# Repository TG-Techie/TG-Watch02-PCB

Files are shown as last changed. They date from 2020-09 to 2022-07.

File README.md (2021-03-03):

# TG-Watch02-PCB
---

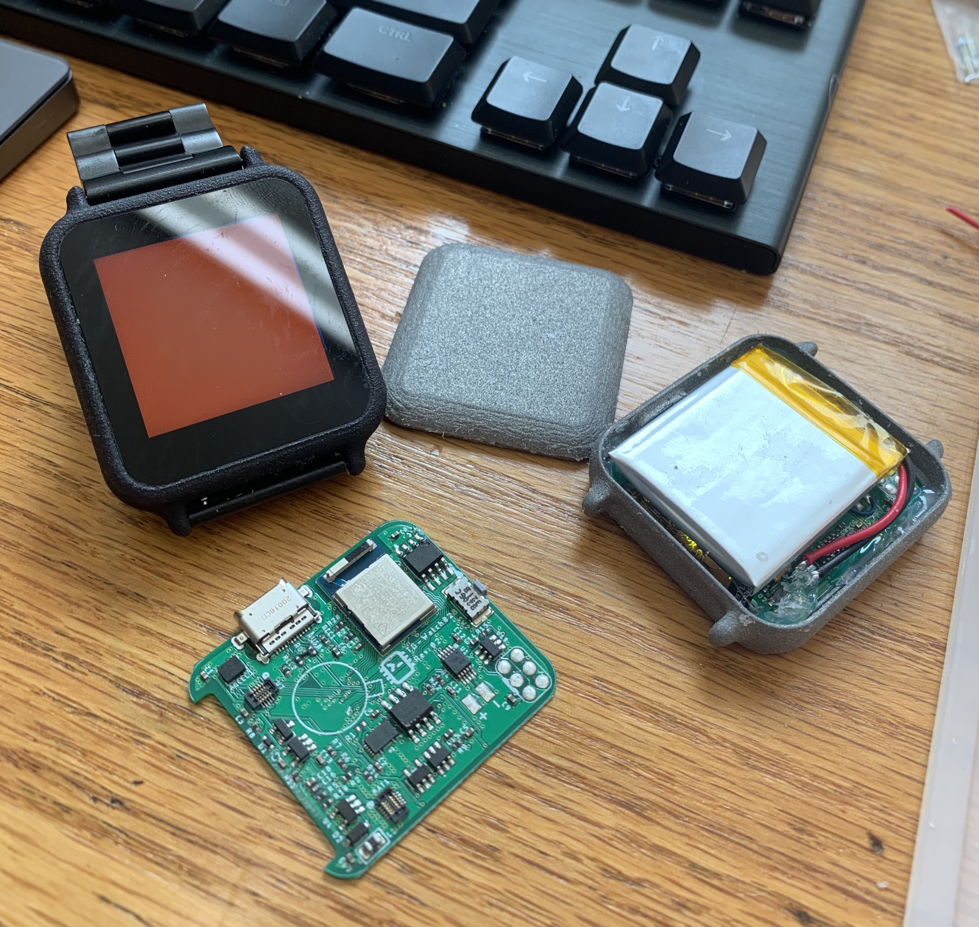
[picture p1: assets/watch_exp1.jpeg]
Image of watch


## Description
Why buy an apple watch when you can spend your weekends building a microcontroller based "smart" watch instead? the TG-Watch is an open source, not-dumb watch meant for makers who want to hack on their watch or as great starting point to learn about programming.

Some of its features include:
- a 240x240, 1.54" lcd
- capacitive touchscreen
- USB Type-C port (2.0)
- Step counter and pedometer
- vibration motor and haptic motor driver
- Bluetooth 5, Bluetooth mesh, Thread, ZigBee

## Software
The TG-Watch was designed to run circuitpython, this gives anyone the flexibility to run what they can write. Additionally, there is on-going development for a python GUI framework (TG-Gui-4 and TG-Gui 5) that runs on the watch. This framework is intended to make writing UI programs to run on the fun and approachable. (Currently under going a re-write)

## Examples
Updates about software and hardware are often posted to twitter, [here](https://twitter.com/TG_Techie).

## What's on it?
- 2295018-2, USB Type-C Connector
- LSM6DSOX, accel & gyro
- DRV2605, Haptic motor driver
- NRF52840, MCU and BLE IC
- BQ27441, battery charge tracker IC
- DS3231, real time clock

## Contribution and Questions
If you have any questions feel free to reach out and start a discussion on twitter at `@TG_Techie` or on discord at `@TG-Techie#5402`.

## License

Design and copyright by Jonah Yolles-Murphy, 2020

Creative Commons Attribution/Share-Alike, all text above must be included in any redistribution. See license.txt for additional details.

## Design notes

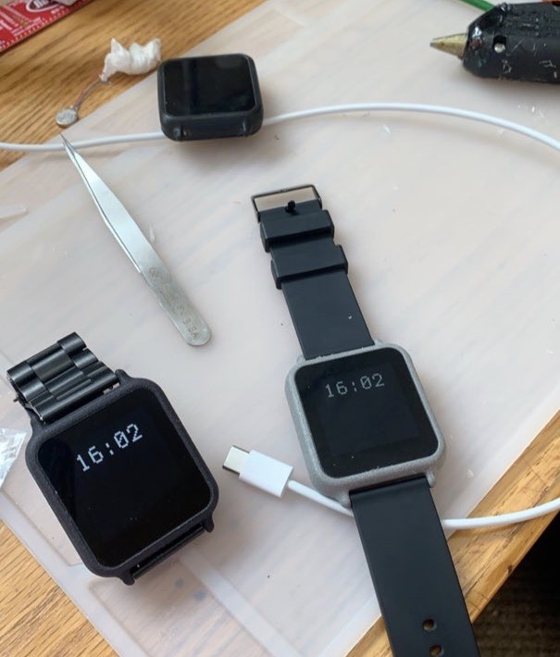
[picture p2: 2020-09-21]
assets/watch_exp0.jpeg

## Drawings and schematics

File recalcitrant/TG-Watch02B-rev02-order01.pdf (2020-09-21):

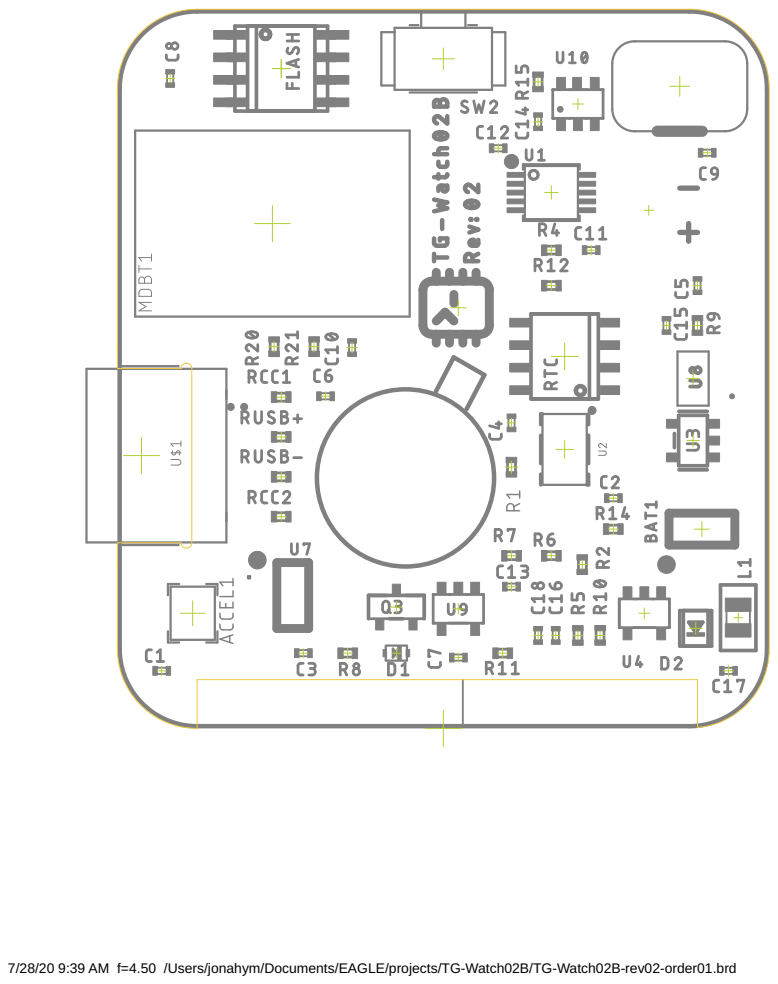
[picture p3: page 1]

7/28/20 9:39 AM f=4.50 /Users/jonahym/Documents/EAGLE/projects/TG-Watch02B/TG-Watch02B-rev02-order01.brd

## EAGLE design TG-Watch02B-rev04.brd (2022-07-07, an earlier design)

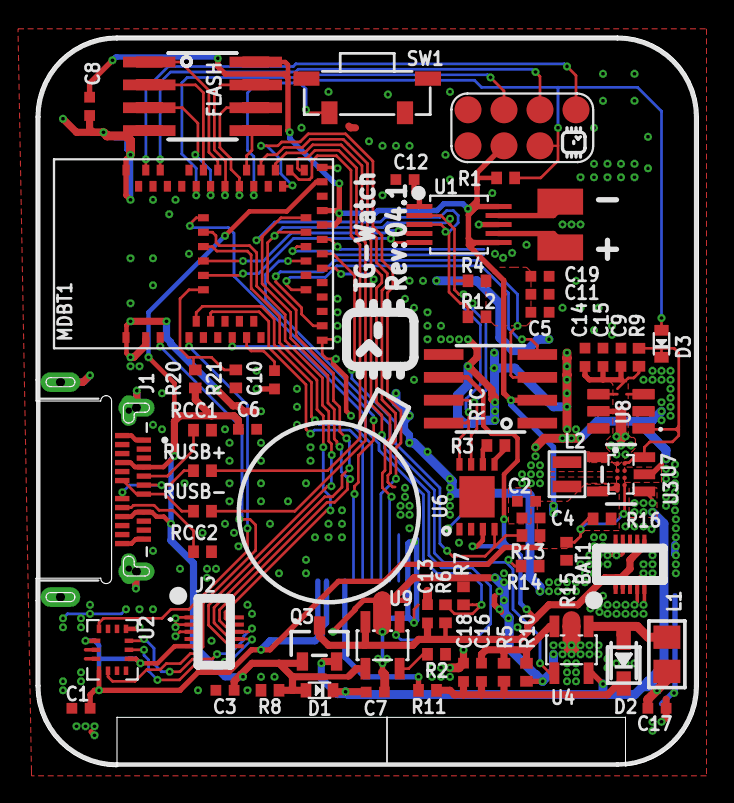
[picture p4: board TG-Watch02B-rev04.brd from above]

Board: 2 copper layers, 36.8 x 40.6 mm, 66 parts (0 on the bottom side), 56 nets.

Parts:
04.1: TG-Watch; TG-PROD-LABEL-5MM
C1, C18: 4.7uf; MICROBUILDER__0402_NODIMS
C2, C3, C4, C5, C6, C7, C8, C9, C13, C14, C15, C17, C19: 10uf; MICROBUILDER__0402_NODIMS
C10: 0.1uF; MICROBUILDER__0402_NODIMS
C11, C12: 1uf; MICROBUILDER__0402_NODIMS
C16: 0.1nF; MICROBUILDER__0402_NODIMS
D1: NSR05T40XV2; SOD-523
D2: BAT54T1G; SOD-323
D3: BAS16XV2T1G; SOD-523
FLASH: W25Q128JVSIQ TR; SOIC8_208MIL
HEDR2: 1X02SMD; 1X2_SMD
IC3: W25Q128JVSIQ TR; SOIC8_150MIL
J1: USB-C-CON-TG_MOD-2295018-2.0; TG_RM_TE_2295018-2
J2: DISP_1.54_LCMTF15423A-C_LCD+CAPTCH_ASSEMBLY_DUALS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; TF-LCM15423A-C_DUALSIDE
J3: CON-BAT-TG-MEZ_FEMALE; MEZ-DF37NC-10DS
L1: 10uH; 0805
L2: 1uH - HMLQ20161B-1R0MDR; NONSTANDARD_INDUCTOR_5
MDBT1: MDBT50
Q3: DMG2305; SOT23-R
R1, R10, R13, R14: 10k; TG_0402
R2: 2k; TG_0402
R3: 11k; TG_0402
R4, R9, R12, R21: 100k; TG_0402
R5: 68k; TG_0402
R6: 270k; TG_0402
R7, R16: 330k; TG_0402
R8: 2.7K; TG_0402
R11: 220R; TG_0402
R15: 59k; TG_0402
R20: 51k; TG_0402
RCC1, RCC2: 5.1k; TG_0402
RTC: SEN-TIME-DS3231-(PERSICION-TEMP); SOIC8_150MIL
RUSB+: 22ohm; TG_0402
RUSB-: 22ohm; TG_0402
SW1: MICROBUILDER_SPST_TACTILE_RA_NO_ALIGN
U1: MICROBUILDER_PSOP10
U2: MICROBUILDER_LSM6DSOX; MICROBUILDER_LGA-14L
U3: VREG-TPS63036; TPS63036YFGR_BGA8N40P4X2_NOSILK
U4: FAN5331SX; SOT23-5@1
U5: MCP73831/OT; SOT23-5L
U6: LC709203F; WDFN8_3X4_0.65
U7: SOT23-5
U8: UNDERVOLT-TPS3702CX3; SOT95P280X110-6N
U$3: CON_SWD_POGO; SWD_POGO

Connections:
3V3: C1.2, C2.2, C4.2, C5.2, C8.2, C11.2, C19.2, FLASH.8, IC3.8, J2.FPC11, J2.FPC12, J2.MEZ5, MDBT1.28, MDBT1.30, R1.2, R4.2, R12.2, R13.1, R16.1, RTC.2, U1.6, U1.10, U2.5, U2.8, U2.12, U3.D1, U7.5, U$3.6
9.6V: C16.1, C18.1, D2.C, R5.2, R11.2
ACCEL_INT1: MDBT1.4, U2.4
ACCEL_INT2: MDBT1.3, U2.9
AREF: C10.2, MDBT1.12
BAT_CHRG_SET: R2.2, U5.5
CC1: J1.A5, RCC1.2
CC2: J1.B5, RCC2.2
D6_BACKLIGHT: MDBT1.23, R14.2, U4.4
D9_RTC_RESET: MDBT1.19, RTC.4
D10_RTC_INT: MDBT1.16, RTC.3
D11_CHRG_STAT: MDBT1.22, U5.1
D12_BAT_INT: MDBT1.24, R13.2, U6.4
D14_VBUS_PRESENT: MDBT1.56, R20.1, R21.2
D15_HAPTIC_ENABLE: MDBT1.57, U1.5
D16_HAPTIC_INT: MDBT1.58, U1.4
D17_CTP_INT: J2.MEZ9, MDBT1.59
D18_CTP_RESET: J2.MEZ6, MDBT1.60
D19_TFT_RESET: J2.FPC8, MDBT1.61
D20_TFT_DC: J2.FPC6, MDBT1.5
D22_TFT_CS: J2.FPC7, MDBT1.7
D+: MDBT1.35, RUSB+.1
D-: MDBT1.34, RUSB-.1
DRV_REG: C12.2, U1.1
GND: C1.1, C2.1, C3.1, C4.1, C5.1, C6.1, C7.1, C8.1, C9.2, C10.1, C11.1, C12.1, C13.1, C14.1, C15.1, C17.1, C18.2, C19.1, FLASH.4, IC3.4, J1.A1, J1.A12, J1.B1, J1.B12, J1.P1_1, J1.P1_2, J1.P2_1, J1.P2_2, J1.P4, J1.P5, J2.FPC1, J2.FPC2, J2.FPC10, J2.MEZ1, J2.MEZ2, J2.MEZ3, J3.P$4, J3.P$5, J3.P$9, J3.P$10, MDBT1.1, MDBT1.2, MDBT1.15, MDBT1.33, MDBT1.55, R2.1, R7.1, R8.1, R10.1, R14.1, R15.1, R21.1, RCC1.1, RCC2.1, RTC.5, SW1.1, U1.8, U2.1, U2.6, U2.7, U3.B2, U3.C2, U4.2, U5.2, U6.1, U6.2, U7.2, U8.2, U$3.1, U$3.5
HAPTIC+: HEDR2.1, U1.7
HAPTIC-: HEDR2.2, U1.9
L1: L2.1, U3.B1
L2: L2.2, U3.C1
MOSI: J2.FPC4, MDBT1.37
unnamed: C16.2, R5.1, R10.2, U4.3
unnamed: D2.A, L1.2, U4.1
QSPI_CS: FLASH.1, IC3.1, MDBT1.44
QSPI_DATA0: FLASH.5, IC3.5, MDBT1.41
QSPI_DATA1: FLASH.2, IC3.2, MDBT1.46
QSPI_DATA2: FLASH.3, IC3.3, MDBT1.45
QSPI_DATA3: FLASH.7, IC3.7, MDBT1.43
QSPI_SCK: FLASH.6, IC3.6, MDBT1.42
RESET: D3.A, MDBT1.40, R1.1, SW1.2, U$3.7
SCK: J2.FPC5, MDBT1.36
SCL: J2.MEZ7, MDBT1.27, R4.1, RTC.8, U1.2, U2.13, U6.8
SDA: J2.MEZ8, MDBT1.29, R12.1, RTC.7, U1.3, U2.14, U6.7
SENSE: R15.2, R16.2, U3.D2
SWDCLK: MDBT1.53, U$3.4
SWDIO: MDBT1.51, U$3.3
SWO: MDBT1.47, U$3.2
SYS_EN: D3.K, R9.1, U3.A2, U7.3, U8.1
TSENSE: R3.2, U6.6
TSW: R3.1, U6.5
USBD+: J1.A6, J1.B6, RUSB+.2
USBD-: J1.A7, J1.B7, RUSB-.2
VBAT: C13.2, J3.P$1, J3.P$2, J3.P$6, J3.P$7, Q3.3, R6.2, RTC.6, U5.3, U6.3
VBUS: C3.2, C6.2, D1.A, J1.A4, J1.A9, J1.B4, J1.B9, MDBT1.32, Q3.1, R8.2, R20.2, U5.4
VDIV: MDBT1.10, R6.1, R7.2
VLED: J2.FPC9, R11.1
VSORS: C7.2, C9.1, C14.2, C15.2, C17.2, D1.K, L1.1, Q3.2, R9.2, U3.A1, U4.5, U7.1, U8.3, U8.4, U8.5

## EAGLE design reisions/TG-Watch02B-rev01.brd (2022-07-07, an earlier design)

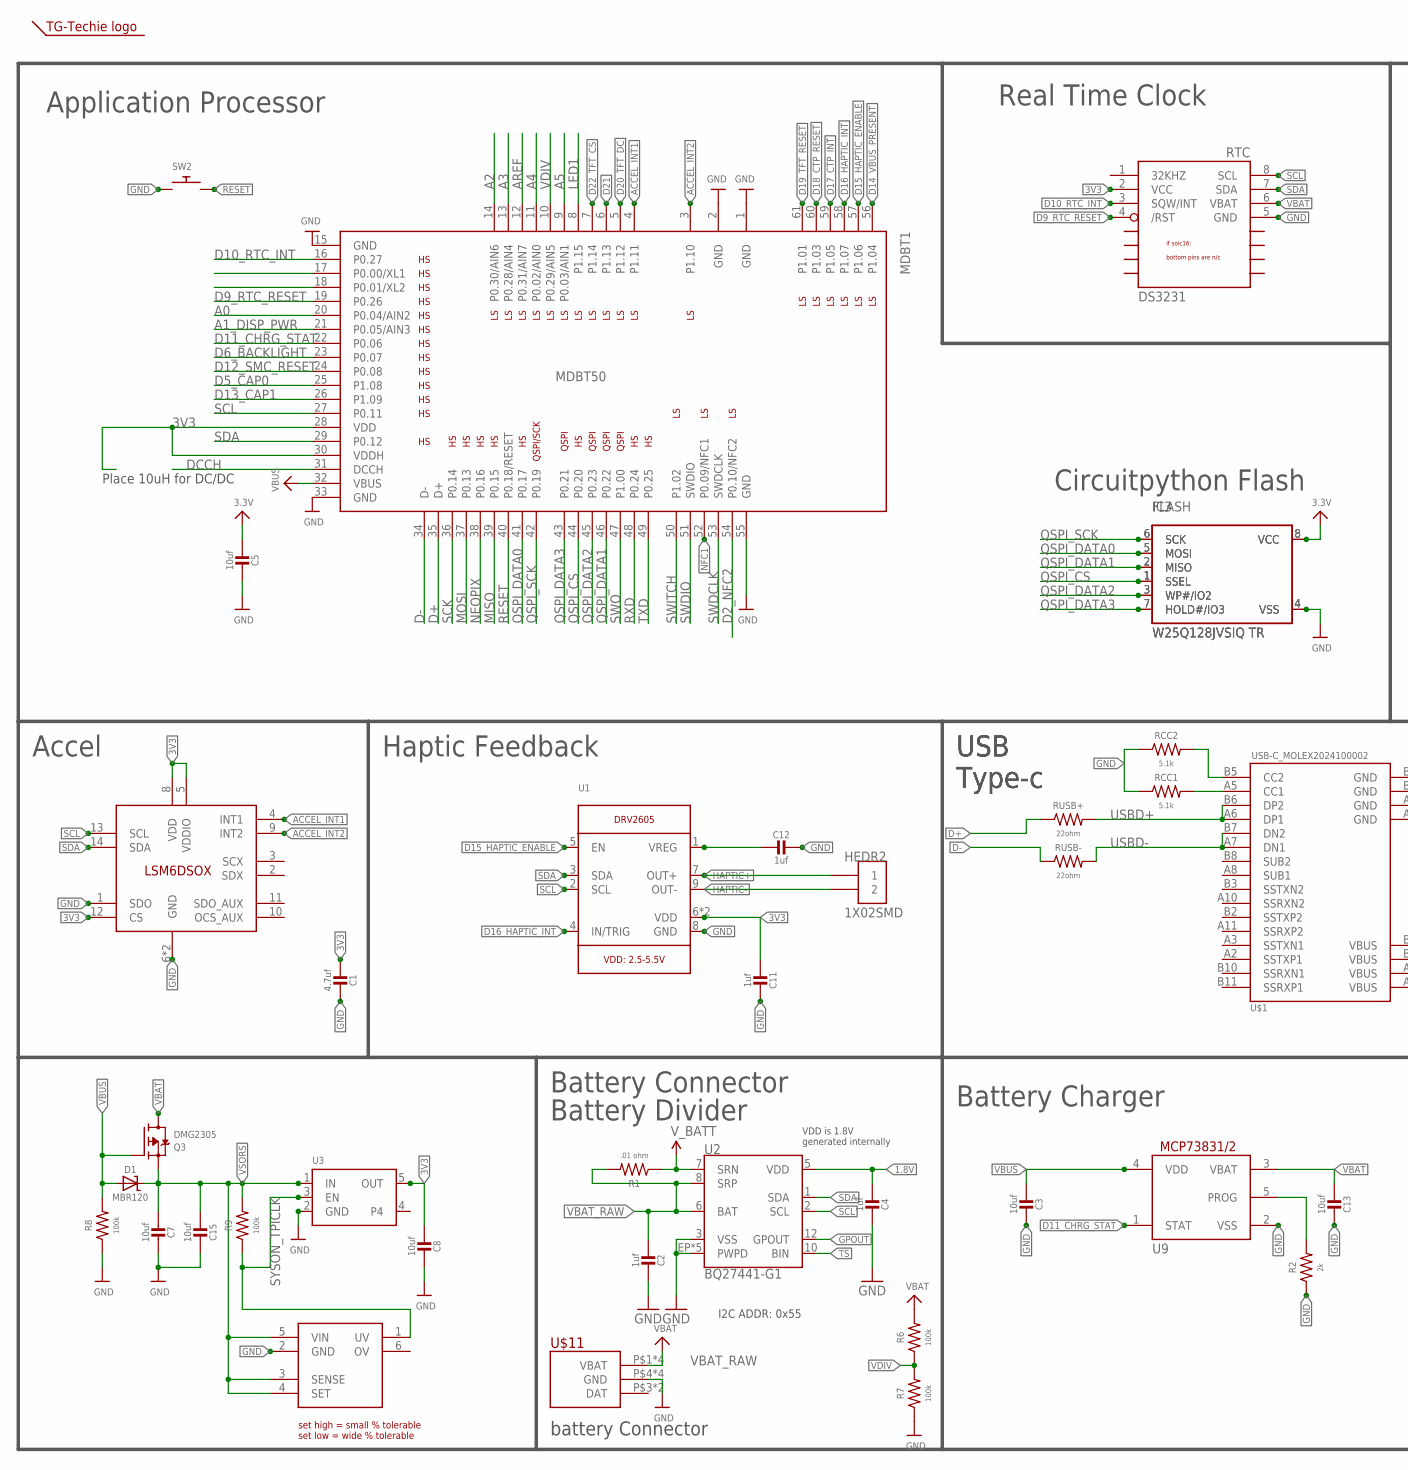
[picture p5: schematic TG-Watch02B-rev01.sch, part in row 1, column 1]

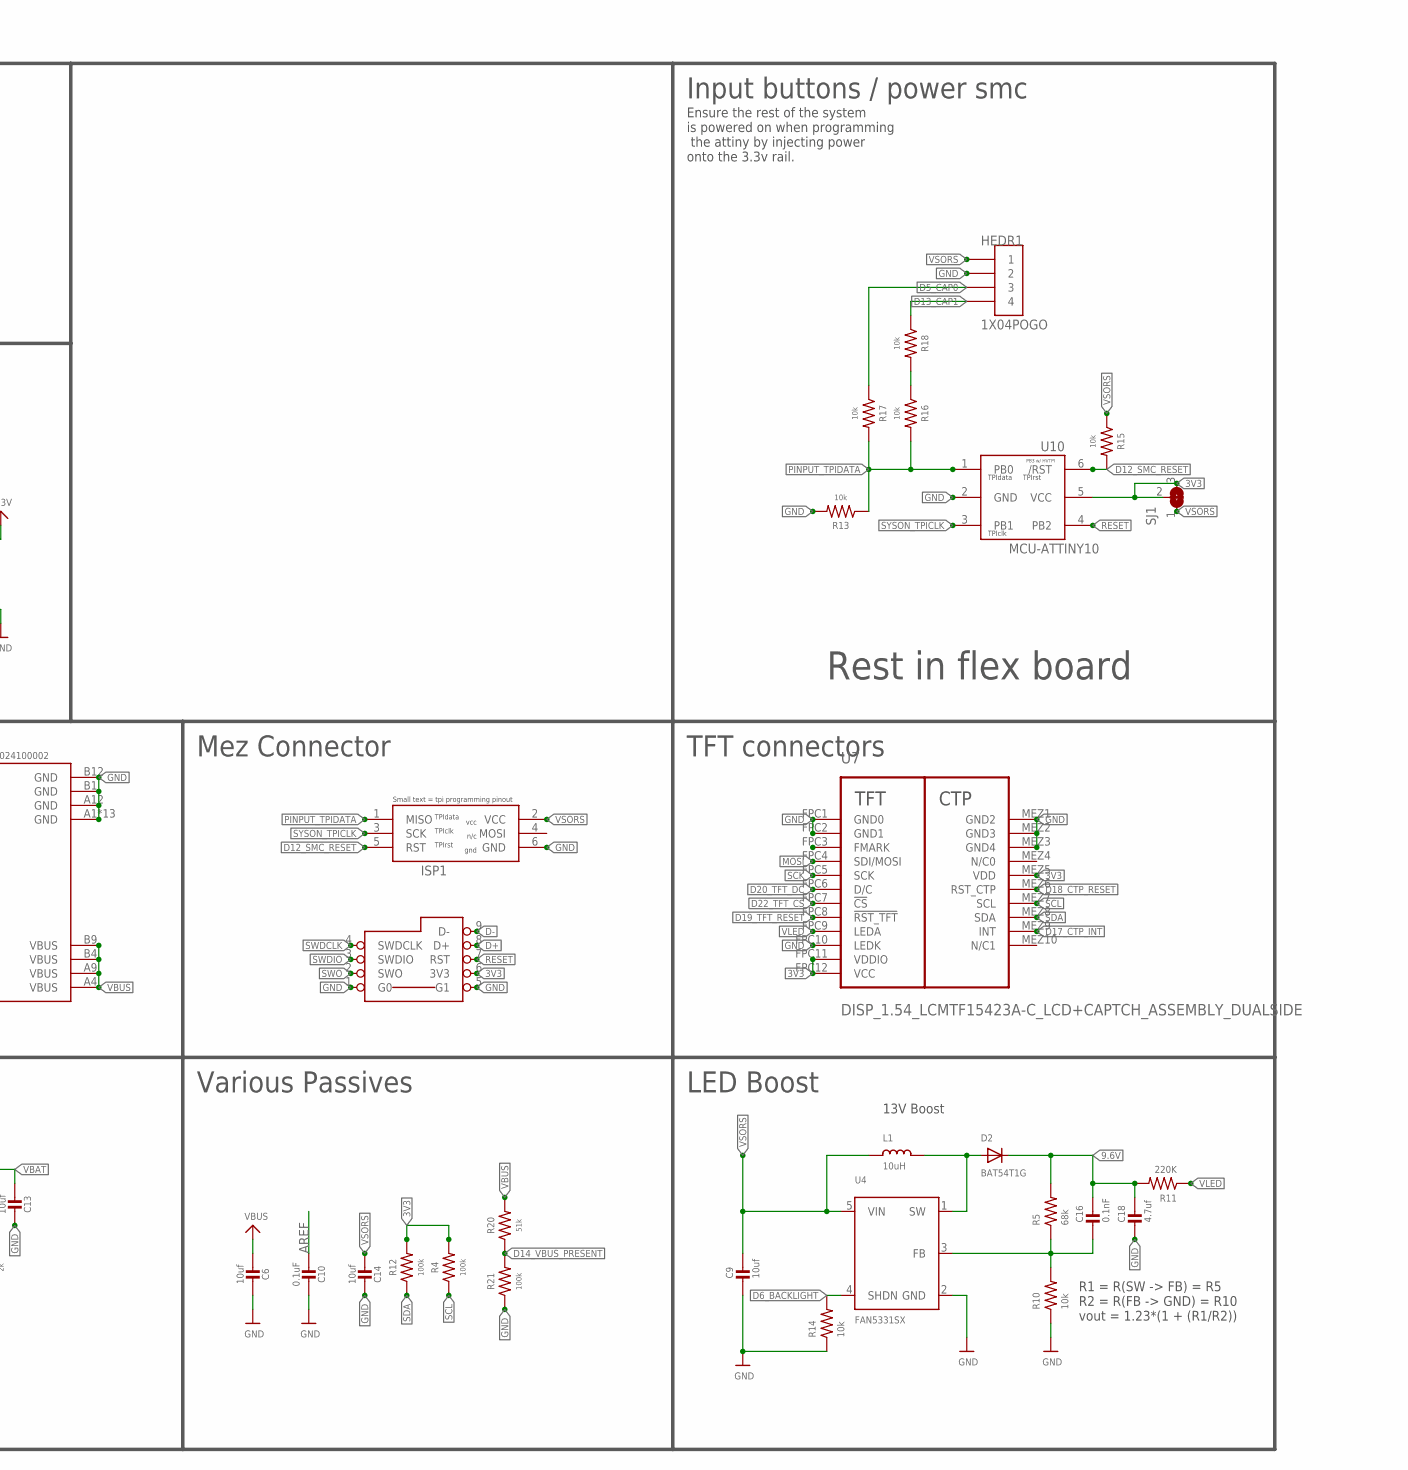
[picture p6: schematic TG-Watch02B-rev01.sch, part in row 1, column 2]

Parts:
C1, C18: 4.7uf; MICROBUILDER__0402_NODIMS
C2, C4, C11, C12: 1uf; MICROBUILDER__0402_NODIMS
C3, C5, C6, C7, C8, C9, C13, C14, C15: 10uf; MICROBUILDER__0402_NODIMS
C10: 0.1uF; MICROBUILDER__0402_NODIMS
C16: 0.1nF; MICROBUILDER__0402_NODIMS
D1: MBR120; SOD-523
D2: BAT54T1G; SOD-523
FLASH: W25Q128JVSIQ TR; SOIC8_208MIL
HEDR1: 1X04POGO; 1X4_POGO
HEDR2: 1X02SMD; 1X2_SMD
IC3: W25Q128JVSIQ TR; SOIC8_150MIL
ISP1: CON-ICSP/ISP-AVR-POGO; 2X3_POGO_AVR
L1: 10uH; 0805
MDBT1: MDBT50
Q3: DMG2305; SOT23-R
R1: .01 ohm; TG_0402
R2: 2k; TG_0402
R4, R6, R7, R8, R9, R12, R21: 100k; TG_0402
R5: 68k; TG_0402
R10, R13, R14, R15, R16, R17, R18: 10k; TG_0402
R11: 220K; TG_0402
R20: 51k; TG_0402
RCC1, RCC2: 5.1k; TG_0402
RTC: SEN-TIME-DS3231-(PERSICION-TEMP); SOIC8_150MIL
RUSB+: 22ohm; TG_0402
RUSB-: 22ohm; TG_0402
SJ1: JUMPER_OPEN_2_OP; SOLDERJUMPER_2WAY_OPEN_NOPASTE
SW2: SWITCH_PUSHBUTTONC&K_KSS; BTN_CK_KSS
U1: HAPTIC_DRIVER_DRV2605_SOP; MICROBUILDER_PSOP10
U2: BQ27441-G1; PDSO-N12
U3: VREG_STD_MIN_SOT23-5; SOT23-5
U4: FAN5331SX; SOT23-5@1
U7: DISP_1.54_LCMTF15423A-C_LCD+CAPTCH_ASSEMBLY_DUALS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; TF-LCM15423A-C_DUALSIDE
U8: UNDERVOLT-TPS3702CX3; SOT95P280X110-6N
U9: MCP73831/OT; SOT23-5L
U10: MCU-ATTINY10; SOT23-6
U$1: USB-C_MOLEX2024100002; USB-C_2024100002_MOLEX
U$3: MICROBUILDER_LSM6DSOX; MICROBUILDER_LGA-14L
U$11: CON-BAT-TG-MEZ_FEMALE; MEZ-DF37NC-10DS
U$13: CON_SWD_POGO_USB; SWD_POGO_USB
U$14: LOGO-TG-TECHIE5MM-SYMB; TG-LOGO-5MM-SYMB

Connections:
1.8V: C4.2, U2.5 (VDD)
3V3: C1.2, C5.2, C8.2, C11.2, FLASH.8 (VCC), IC3.8 (VCC), MDBT1.28 (VDD), MDBT1.30 (VDDH), R4.2, R12.2, RTC.2 (VCC), SJ1.2, SJ1.3, U1.6 (VDD), U1.10 (VDD), U3.5 (OUT), U7.FPC11 (VDDIO), U7.FPC12 (VCC), U7.MEZ5 (VDD), U10.5 (VCC), U$3.5 (VDDIO), U$3.8 (VDD), U$3.12 (CS), U$13.6 (3V3)
9.6V: C16.1, C18.1, D2.K (C), R5.2, R11.2
A0: MDBT1.20 (P0.04/AIN2)
A1_DISP_PWR: MDBT1.21 (P0.05/AIN3)
A2: MDBT1.14 (P0.30/AIN6)
A3: MDBT1.13 (P0.28/AIN4)
A4: MDBT1.11 (P0.02/AIN0)
A5: MDBT1.9 (P0.03/AIN1)
ACCEL_INT1: MDBT1.4 (P1.11), U$3.4 (INT1)
ACCEL_INT2: MDBT1.3 (P1.10), U$3.9 (INT2)
AREF: C10.2, MDBT1.12 (P0.31/AIN7)
BAT_CHRG_SET: R2.2, U9.5 (PROG)
CC1: RCC1.2, U$1.A5 (CC1)
CC2: RCC2.2, U$1.B5 (CC2)
D2_NFC2: MDBT1.54 (P0.10/NFC2)
D5_CAP0: HEDR1.3, MDBT1.25 (P1.08), R17.1
D6_BACKLIGHT: MDBT1.23 (P0.07), R14.2, U4.4 (SHDN)
D9_RTC_RESET: MDBT1.19 (P0.26), RTC.4 (/RST)
D10_RTC_INT: MDBT1.16 (P0.27), RTC.3 (SQW/INT)
D11_CHRG_STAT: MDBT1.22 (P0.06), U9.1 (STAT)
D12_SMC_RESET: ISP1.5 (RST), MDBT1.24 (P0.08), R15.2, U10.6 (/RST)
D13_CAP1: HEDR1.4, MDBT1.26 (P1.09), R18.1
D14_VBUS_PRESENT: MDBT1.56 (P1.04), R20.1, R21.2
D15_HAPTIC_ENABLE: MDBT1.57 (P1.06), U1.5 (EN)
D16_HAPTIC_INT: MDBT1.58 (P1.07), U1.4 (IN/TRIG)
D17_CTP_INT: MDBT1.59 (P1.05), U7.MEZ9 (INT)
D18_CTP_RESET: MDBT1.60 (P1.03), U7.MEZ6 (RST_CTP)
D19_TFT_RESET: MDBT1.61 (P1.01), U7.FPC8 (!RST_TFT)
D20_TFT_DC: MDBT1.5 (P1.12), U7.FPC6 (D/C)
D21: MDBT1.6 (P1.13)
D22_TFT_CS: MDBT1.7 (P1.14), U7.FPC7 (!CS)
D+: MDBT1.35 (D+), RUSB+.1, U$13.8 (D+)
D-: MDBT1.34 (D-), RUSB-.1, U$13.9 (D-)
DCCH: MDBT1.31 (DCCH)
DRV_REG: C12.2, U1.1 (VREG)
GND: C1.1, C2.1, C3.1, C4.1, C5.1, C6.1, C7.1, C8.1, C9.2, C10.1, C11.1, C12.1, C13.1, C14.1, C15.1, C18.2, FLASH.4 (VSS), HEDR1.2, IC3.4 (VSS), ISP1.6 (GND), MDBT1.1 (GND), MDBT1.2 (GND), MDBT1.15 (GND), MDBT1.33 (GND), MDBT1.55 (GND), R2.1, R7.1, R8.1, R10.1, R13.2, R14.1, R21.1, RCC1.1, RCC2.1, RTC.5 (GND), SW2.P$1, U1.8 (GND), U2.3 (VSS), U2.EP (PWPD), U2.EP1 (PWPD), U2.EP2 (PWPD), U2.EP3 (PWPD), U2.EP4 (PWPD), U3.2 (GND), U4.2 (GND), U7.FPC1 (GND0), U7.FPC2 (GND1), U7.FPC10 (LEDK), U7.MEZ1 (GND2), U7.MEZ2 (GND3), U7.MEZ3 (GND4), U8.2 (GND), U9.2 (VSS), U10.2 (GND), U$1.A1 (GND), U$1.A12 (GND), U$1.B1 (GND), U$1.B12 (GND), U$1.P$1 (GND), U$1.P$2 (GND), U$1.P$3 (GND), U$1.P$4 (GND), U$1.P$5 (GND), U$1.P$6 (GND), U$1.P$7 (GND), U$1.P$8 (GND), U$1.SHLD0 (GND), U$1.SHLD1 (GND), U$1.SHLD2 (GND), U$1.SHLD3 (GND), U$3.1 (SDO), U$3.6 (GND), U$3.7 (GND), U$11.P$4 (GND), U$11.P$5 (GND), U$11.P$9 (GND), U$11.P$10 (GND), U$13.1 (G0), U$13.5 (G1)
GPOUT: U2.12 (GPOUT)
HAPTIC+: HEDR2.1, U1.7 (OUT+)
HAPTIC-: HEDR2.2, U1.9 (OUT-)
LED1: MDBT1.8 (P1.15)
MISO: MDBT1.39 (P0.15)
MOSI: MDBT1.37 (P0.13), U7.FPC4 (SDI/MOSI)
unnamed: C16.2, R5.1, R10.2, U4.3 (FB)
unnamed: D2.A, L1.2, U4.1 (SW)
unnamed: R16.1, R18.2
NEOPIX: MDBT1.38 (P0.16)
NFC1: MDBT1.52 (P0.09/NFC1)
PINPUT_TPIDATA: ISP1.1 (MISO), R13.1, R16.2, R17.2, U10.1 (PB0)
QSPI_CS: FLASH.1 (SSEL), IC3.1 (SSEL), MDBT1.44 (P0.20)
QSPI_DATA0: FLASH.5 (MOSI), IC3.5 (MOSI), MDBT1.41 (P0.17)
QSPI_DATA1: FLASH.2 (MISO), IC3.2 (MISO), MDBT1.46 (P0.22)
QSPI_DATA2: FLASH.3 (WP#/IO2), IC3.3 (WP#/IO2), MDBT1.45 (P0.23)
QSPI_DATA3: FLASH.7 (HOLD#/IO3), IC3.7 (HOLD#/IO3), MDBT1.43 (P0.21)
QSPI_SCK: FLASH.6 (SCK), IC3.6 (SCK), MDBT1.42 (P0.19)
RESET: MDBT1.40 (P0.18/RESET), SW2.P$2, U10.4 (PB2), U$13.7 (RST)
RXD: MDBT1.48 (P0.24)
SCK: MDBT1.36 (P0.14), U7.FPC5 (SCK)
SCL: MDBT1.27 (P0.11), R4.1, RTC.8 (SCL), U1.2 (SCL), U2.2 (SCL), U7.MEZ7 (SCL), U$3.13 (SCL)
SDA: MDBT1.29 (P0.12), R12.1, RTC.7 (SDA), U1.3 (SDA), U2.1 (SDA), U7.MEZ8 (SDA), U$3.14 (SDA)
SWDCLK: MDBT1.53 (SWDCLK), U$13.4 (SWDCLK)
SWDIO: MDBT1.51 (SWDIO), U$13.3 (SWDIO)
SWITCH: MDBT1.50 (P1.02)
SWO: MDBT1.47 (P1.00), U$13.2 (SWO)
SYSON_TPICLK: ISP1.3 (SCK), R9.1, U3.3 (EN), U8.1 (UV), U10.3 (PB1)
TS: U2.10 (BIN)
TXD: MDBT1.49 (P0.25)
USBD+: RUSB+.2, U$1.A6 (DP1), U$1.B6 (DP2)
USBD-: RUSB-.2, U$1.A7 (DN1), U$1.B7 (DN2)
VBAT: C13.2, Q3.3 (D), R1.1, R6.2, RTC.6 (VBAT), U2.7 (SRN), U9.3 (VBAT)
VBAT_RAW: C2.2, R1.2, U2.6 (BAT), U2.8 (SRP), U$11.P$1 (VBAT), U$11.P$2 (VBAT), U$11.P$6 (VBAT), U$11.P$7 (VBAT)
VBUS: C3.2, C6.2, D1.A, MDBT1.32 (VBUS), Q3.1 (G), R8.2, R20.2, U9.4 (VDD), U$1.A4 (VBUS), U$1.A9 (VBUS), U$1.B4 (VBUS), U$1.B9 (VBUS)
VDIV: MDBT1.10 (P0.29/AIN5), R6.1, R7.2
VLED: R11.1, U7.FPC9 (LEDA)
VSORS: C7.2, C9.1, C14.2, C15.2, D1.K (C), HEDR1.1, ISP1.2 (VCC), L1.1, Q3.2 (S), R9.2, R15.1, SJ1.1, U3.1 (IN), U4.5 (VIN), U8.3 (SENSE), U8.4 (SET), U8.5 (VIN)

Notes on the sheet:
Place 10uH for DC/DC
13V Boost
R1 = R(SW -> FB) = R5 R2 = R(FB -> GND) = R10 vout = 1.23*(1 + (R1/R2))
battery Connector
Battery Connector
Battery Divider
Battery Charger
Various Passives
Mez Connector
TFT connectors
LED Boost
USB Type-c
Haptic Feedback
Accel
Circuitpython Flash
Input buttons / power smc
Application Processor
Ensure the rest of the system is powered on when programming the attiny by injecting power onto the 3.3v rail.
Rest in flex board
Real Time Clock
VDD is 1.8V generated internally
I2C ADDR: 0x55

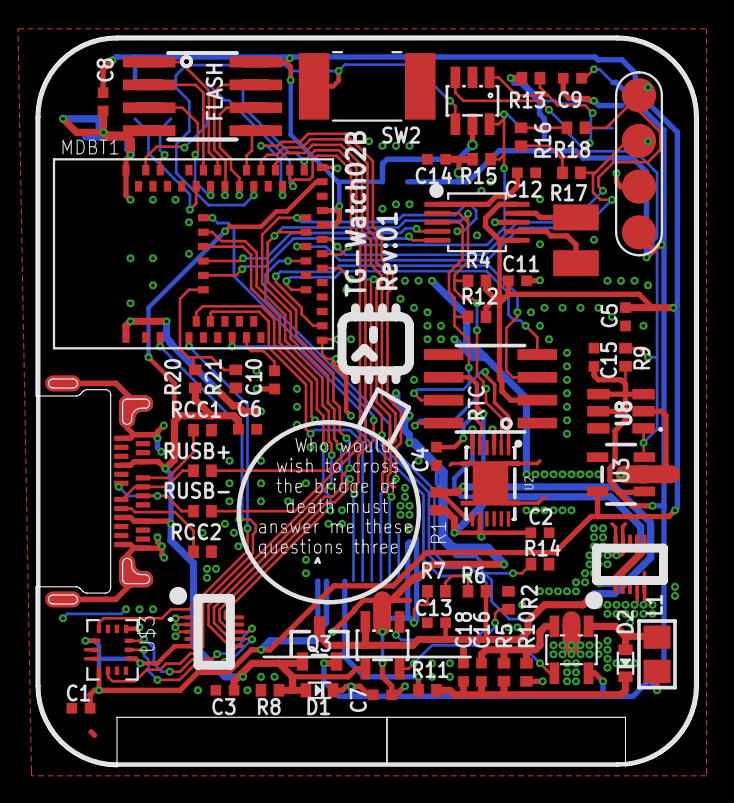
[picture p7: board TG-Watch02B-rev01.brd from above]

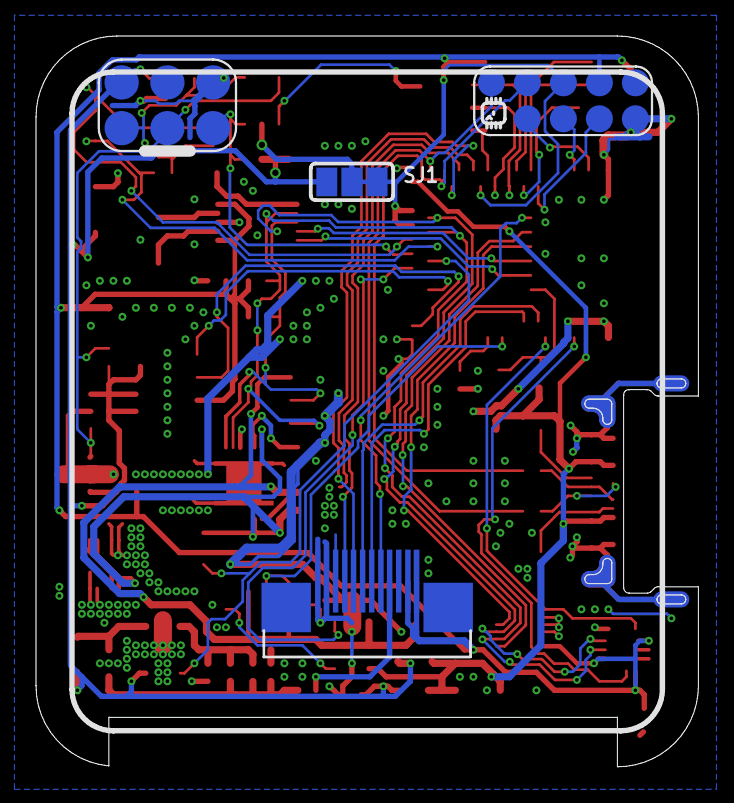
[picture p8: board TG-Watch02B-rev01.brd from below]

Board: 2 copper layers, 36.8 x 40.6 mm, 66 parts (3 on the bottom side), 57 nets.

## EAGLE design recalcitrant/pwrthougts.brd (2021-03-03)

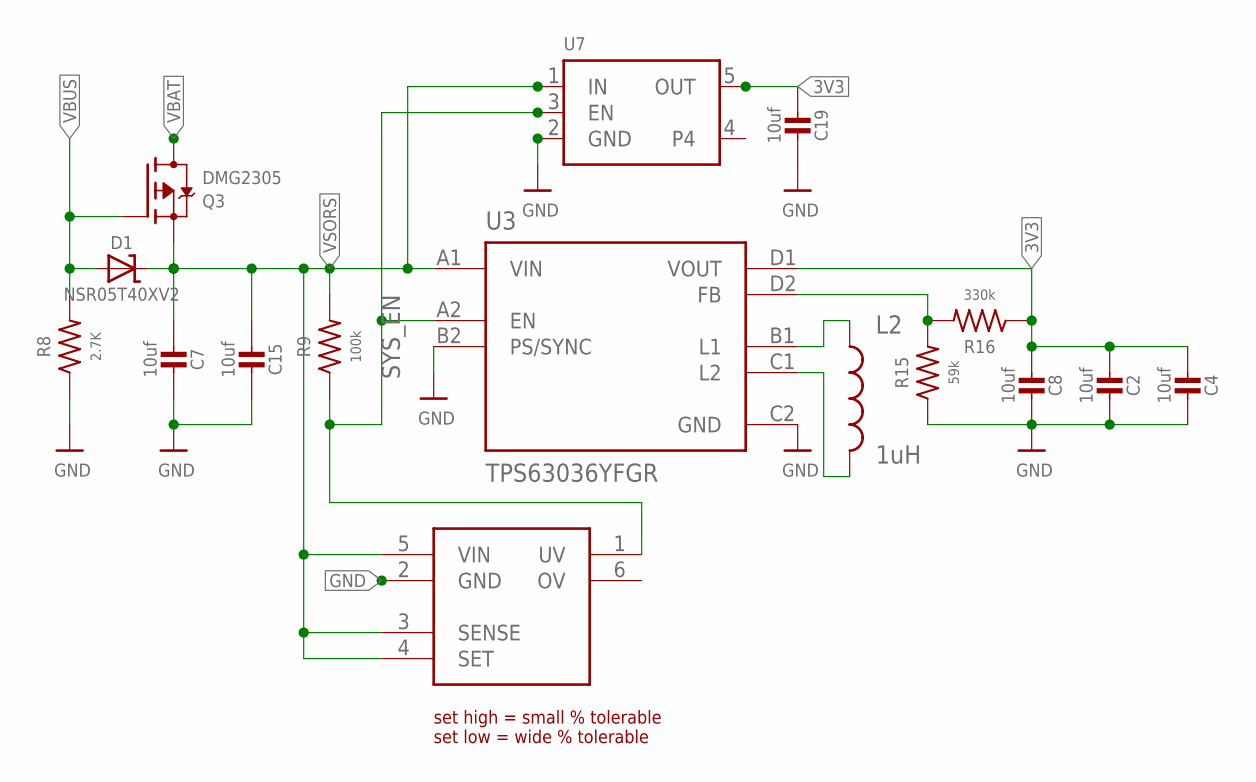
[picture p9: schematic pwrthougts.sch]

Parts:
C2, C4, C7, C8, C15, C19: 10uf; MICROBUILDER__0402_NODIMS
D1: NSR05T40XV2; SOD-523
L2: 1uH; NONSTANDARD_INDUCTOR_5
Q3: DMG2305; SOT23-R
R8: 2.7K; TG_0402
R9: 100k; TG_0402
R15: 59k; TG_0402
R16: 330k; TG_0402
U3: TPS63036YFGR; BGA8N40P4X2_181X107X62N
U7: VREG_STD_MIN_SOT23-5; SOT23-5
U8: UNDERVOLT-TPS3702CX3; SOT95P280X110-6N

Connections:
3V3: C2.2, C4.2, C8.2, C19.2, R16.1, U3.D1 (VOUT), U7.5 (OUT)
GND: C2.1, C4.1, C7.1, C8.1, C15.1, C19.1, R8.1, R15.1, U3.B2 (PS/SYNC), U3.C2 (GND), U7.2 (GND), U8.2 (GND)
L1: L2.1, U3.B1 (L1)
L2: L2.2, U3.C1 (L2)
SENSE: R15.2, R16.2, U3.D2 (FB)
SYS_EN: R9.1, U3.A2 (EN), U7.3 (EN), U8.1 (UV)
VBAT: Q3.3 (D)
VBUS: D1.A, Q3.1 (G), R8.2
VSORS: C7.2, C15.2, D1.K (C), Q3.2 (S), R9.2, U3.A1 (VIN), U7.1 (IN), U8.3 (SENSE), U8.4 (SET), U8.5 (VIN)

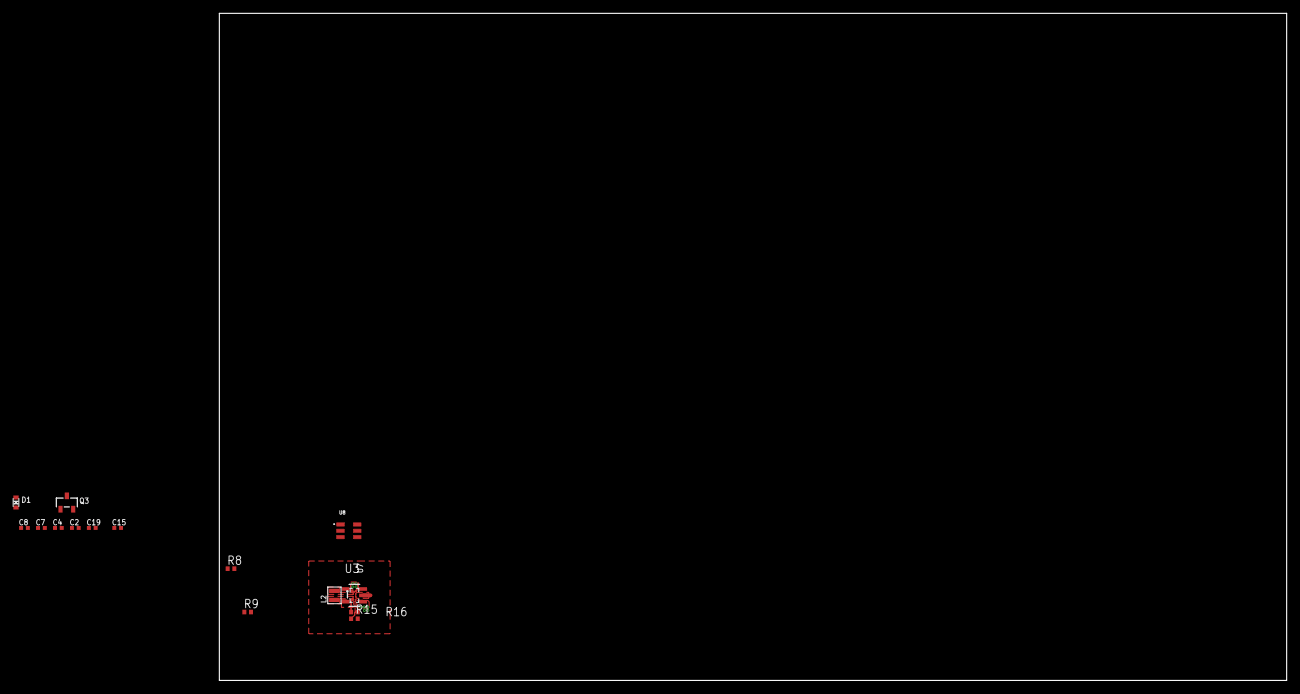
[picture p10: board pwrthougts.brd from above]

Board: 2 copper layers, 160.0 x 100.0 mm, 16 parts (0 on the bottom side), 8 nets.

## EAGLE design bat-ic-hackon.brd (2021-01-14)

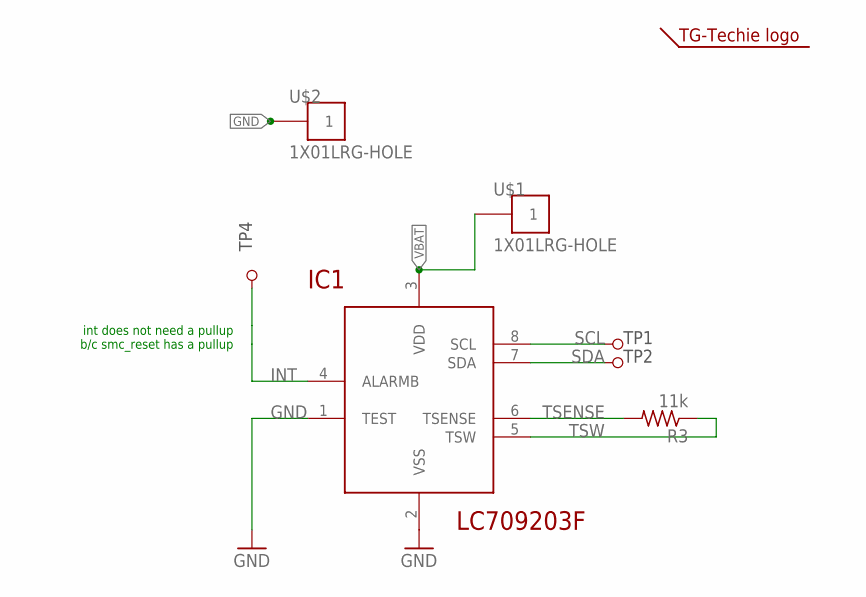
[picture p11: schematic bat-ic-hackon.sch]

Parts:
IC1: LC709203F; WDFN8_3X4_0.65
R3: 11k; TG_0402
TP1, TP2, TP4: TESTPOINT_1X1_SMALL; 1X1_POGO_SMALL
U$1, U$2: 1X01LRG-HOLE; 1X1_HOLE_LRG
U$3: LOGO-TG-TECHIE5MM-SYMB; TG-LOGO-5MM-SYMB

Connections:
GND: IC1.1 (TEST), IC1.2 (VSS), U$2.1
INT: IC1.4 (ALARMB), TP4.1
SCL: IC1.8 (SCL), TP1.1
SDA: IC1.7 (SDA), TP2.1
TSENSE: IC1.6 (TSENSE), R3.2
TSW: IC1.5 (TSW), R3.1
VBAT: IC1.3 (VDD), U$1.1

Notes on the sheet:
int does not need a pullup b/c smc_reset has a pullup

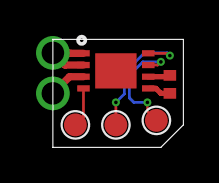
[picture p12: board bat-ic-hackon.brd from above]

Board: 2 copper layers, 7.2 x 6.0 mm, 8 parts (1 on the bottom side), 7 nets.

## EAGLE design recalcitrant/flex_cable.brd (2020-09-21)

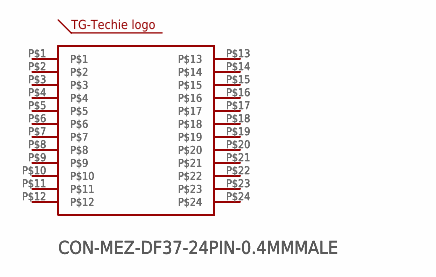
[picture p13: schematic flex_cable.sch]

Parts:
U$1, U$11: CON-MEZ-DF37-24PIN-0.4MMMALE; MEZ-DF37B-24DP
U$2: LOGO-TG-TECHIE5MM; TG-LOGO-5MM

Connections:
unnamed: U$1.P$1, U$11.P$1
unnamed: U$1.P$2, U$11.P$2
unnamed: U$1.P$3, U$11.P$3
unnamed: U$1.P$4, U$11.P$4
unnamed: U$1.P$5, U$11.P$5
unnamed: U$1.P$6, U$11.P$6
unnamed: U$1.P$7, U$11.P$7
unnamed: U$1.P$8, U$11.P$8
unnamed: U$1.P$9, U$11.P$9
unnamed: U$1.P$10, U$11.P$10
unnamed: U$1.P$11, U$11.P$11
unnamed: U$1.P$12, U$11.P$12
unnamed: U$1.P$13, U$11.P$13
unnamed: U$1.P$14, U$11.P$14
unnamed: U$1.P$15, U$11.P$15
unnamed: U$1.P$16, U$11.P$16
unnamed: U$1.P$17, U$11.P$17
unnamed: U$1.P$18, U$11.P$18
unnamed: U$1.P$19, U$11.P$19
unnamed: U$1.P$20, U$11.P$20
unnamed: U$1.P$21, U$11.P$21
unnamed: U$1.P$22, U$11.P$22
unnamed: U$1.P$23, U$11.P$23
unnamed: U$1.P$24, U$11.P$24

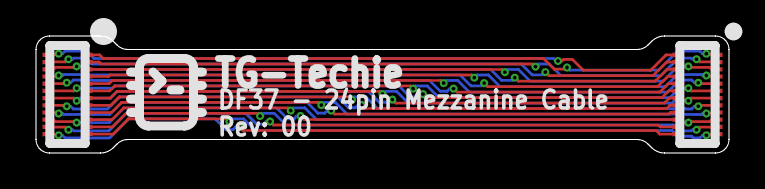
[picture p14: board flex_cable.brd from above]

Board: 2 copper layers, 38.5 x 6.5 mm, 3 parts (0 on the bottom side), 24 nets.

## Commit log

2020-09-21 init commit
    [TG-Watch02A-Flex-v2.brd, TG-Watch02A-Flex-v2.sch, TG-Watch02B-rev00.brd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]
2021-01-14 chagne battery IC and make path for rev02 boards
    [TG-Watch02B-rev04.brd, TG-Watch02B-rev04.sch, bat-ic-hackon.brd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]

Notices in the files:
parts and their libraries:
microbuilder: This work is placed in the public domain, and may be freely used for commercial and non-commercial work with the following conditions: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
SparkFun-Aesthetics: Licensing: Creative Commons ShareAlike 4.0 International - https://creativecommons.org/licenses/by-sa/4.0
